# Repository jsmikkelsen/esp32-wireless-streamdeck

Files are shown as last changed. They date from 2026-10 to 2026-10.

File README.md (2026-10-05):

# ESP32 Trådløs Stream Deck & Audio Mixer

Et trådløst, tilpasseligt DIY Stream Deck og 4-kanals audio mixer bygget på en **ESP32**, **12x MX-taster** (i 3x4 anti-ghosting matrix med dioder), **4x potentiometre** og et **SSD1306 128x64 OLED-display**.

Projektet forbinder trådløst til din PC via Wi-Fi og en ultra-lav latens WebSocket-forbindelse. Du kan give enheden strøm fra en hvilken som helst 5V USB-oplader eller powerbank – **uden at have et kabel i computeren**.

---

## 🌟 Nøglefunktioner

* **Trådløs frihed:** Kører over lokalt Wi-Fi (svartid typisk 2-5 ms).
* **4-kanals hardware mixer:** Fysiske drejeknapper til individuel styring af f.eks. Master, Discord, Spotify og Browser.
* **Dynamisk OLED-dashboard:** 128x64 display viser 4 vertikale volumensøjler med live procenttal og kanalnavne.
* **12 programmerbare MX-taster:** 3x4 matrix med 1N4148-dioder for fuld anti-ghosting (N-key rollover).
* **Ingen gen-flashing påkrævet:** Handlinger og app-lydstyring konfigureres i `config.json` på din PC. Ret filen, og ændringerne træder i kraft med det samme!
* **Støjfri potentiometre:** Softwaren benytter Exponential Moving Average (EMA) filtrering og deadband, så lydstyrken aldrig flimrer.

---

## 📁 Projektstruktur

```text
esp32-wireless-streamdeck/
├── 3D/                           # 3D-filer til kabinet (STL, OpenSCAD og generator)
│   ├── streamdeck_top_plate.stl  # Topplade klar til 3D-print
│   ├── streamdeck_bottom_case.stl# Bundkabinet med USB-port klar til 3D-print
│   ├── generate_case.py          # Python STL generator
│   ├── streamdeck_case.scad      # Parametrisk OpenSCAD kildekode
│   └── README.md                 # Print- og monteringsvejledning
├── docs/
│   └── WIRING.md                 # Komplet lodde- og kablingsguide med diagrammer
├── firmware/
│   ├── platformio.ini            # PlatformIO projektfil
│   ├── src/
│   │   └── main.cpp              # C++ firmware kildekode
│   └── firmware.ino              # Samme firmware som Arduino IDE sketch
├── pc_server/
│   ├── config.json               # Konfiguration af taster og lydkanaler (ret her!)
│   ├── requirements.txt          # Python afhængigheder
│   └── streamdeck_server.py      # Baggrundsserver på PC (WebSocket + Audio + Hotkeys)
├── .gitignore
└── README.md
```

---

## 🛠️ Hardware Komponenter

1. **ESP32 DevKit** (NodeMCU-32S / ESP32-WROOM-32)
2. **12x Cherry MX kompatible switches**
3. **12x Dioder** (f.eks. 1N4148)
4. **4x Drejepotentiometre** (10k lineære)
5. **1x 0.96" I2C OLED display (SSD1306 128x64)**

Se [docs/WIRING.md](docs/WIRING.md) for detaljerede instruktioner om pin-forbindelser og lodning.

---

## 🚀 Hurtigstart Guide

### Trin 1: Kabling
Følg oversigten i [docs/WIRING.md](docs/WIRING.md).
* **Vigtigt:** Potentiometre forbindes til **3.3V** og ADC1-pinnene (**GPIO 32, 33, 34, 35**).
* **OLED:** SDA -> GPIO 21, SCL -> GPIO 22.

---

### Trin 2: Flash ESP32 Firmware

Åbn projektet i **PlatformIO** (VS Code) eller **Arduino IDE**:

1. Åbn `firmware/src/main.cpp` (eller `firmware/firmware.ino`).
2. Ret Wi-Fi oplysningerne og din PC's lokale IP-adresse:
   ```cpp
   const char* WIFI_SSID     = "DIT_WIFI_NAVN";      // 2.4 GHz Wi-Fi netværk
   const char* WIFI_PASSWORD = "DIT_WIFI_KODE";
   const char* PC_HOST       = "192.168.1.100";     // Din PC's lokale IPv4 adresse
   const int   WS_PORT       = 8765;
   ```
3. Upload koden til din ESP32.

> **Biblioteker til Arduino IDE:**
> * `Adafruit SSD1306` & `Adafruit GFX Library`
> * `WebSockets` af Markus Sattler
> * `ArduinoJson` (v6 eller nyere)

---

### Trin 3: Start PC Companion Serveren

På din PC (Windows anbefales for app-volumen):

1. Åbn en terminal / kommandoprompt i mappen `pc_server/`.
2. Installer kravene:
   ```bash
   pip install -r requirements.txt
   ```
3. Start serveren:
   ```bash
   python streamdeck_server.py
   ```
Serveren lytter nu på port `8765`. Når din ESP32 tænder, forbinder den automatisk, og skærmen opdateres!

---

### Trin 4: Tilpas dine taster og lydkanaler

Åbn `pc_server/config.json` i din foretrukne teksteditor:

```json
{
  "channels": [
    { "label": "MST", "target": "master" },
    { "label": "DIS", "target": "discord.exe" },
    { "label": "SPT", "target": "spotify.exe" },
    { "label": "APP", "target": "chrome.exe" }
  ],
  "keys": {
    "1": { "name": "Play/Pause", "action": "media_play_pause" },
    "2": { "name": "Mute Mic", "action": "hotkey", "keys": ["ctrl", "shift", "m"] },
    "3": { "name": "Lommeregner", "action": "launch", "cmd": "calc.exe" }
  }
}
```

* **Understøttede handlinger for taster:**
  * `"action": "hotkey"` med `"keys": ["ctrl", "alt", "del"]`
  * `"action": "media_play_pause"`, `"media_next"`, `"media_prev"`, `"media_mute"`
  * `"action": "launch"` med et vilkårligt program eller script i `"cmd"`

---

## 🔍 Fejlfinding

* **ESP32 kan ikke forbinde til Wi-Fi:**
  * ESP32 understøtter kun **2.4 GHz Wi-Fi** (ikke 5 GHz). Sørg for at dit netværk udsender 2.4 GHz.
* **ESP32 viser "Connecting..." på skærmen:**
  * Tjek at `PC_HOST` i firmwaren matcher computerens IP (`ipconfig` i Windows kommandoprompt).
  * Tjek at Windows Firewall ikke blokerer for port `8765`.
* **Potentiometer-værdier virker ikke under Wi-Fi:**
  * Sørg for at potentiometrene er forbundet til GPIO 32-35 (ADC1). Pins på ADC2 (f.eks. GPIO 2, 4, 12-15) virker ikke når Wi-Fi er tændt.

---

## 📜 Licens
MIT

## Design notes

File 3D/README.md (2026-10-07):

# 3D Print Ergonomisk Kabinet (Wedge Enclosure)

Denne mappe indeholder de færdige 3D-filer samt kildekoden til det vinklede skrivebordskabinet til **ESP32 Wireless Stream Deck & Audio Mixer**.

Designet er udformet som en klassisk ergonomisk **wedge/kile** med en hældningsvinkel på ca. **22 grader** mod brugeren, præcis som professionelle Stream Decks og macropads:

* **Ergonomisk vinkel:** Lav forkant (**18 mm**) for behagelig håndstilling og høj bagkant (**50 mm**) for optimal synsvinkel til OLED-displayet og tasterne.
* **Planforsænket topplade:** Toppladen med taster og potentiometre hviler på en 3 mm forsænket indvendig hylde med en flot omkransende kant.
* **Layout (venstre):** 12x Cherry MX switches i 4x3 matrix (14.2 mm snap-fit huller med standard 19.05 mm pitch).
* **Layout (højre):**
  * **Øverst:** 2x Potentiometre (Master & Discord) med 7.5 mm huller.
  * **Midt:** 1x 0.96" SSD1306 OLED-display (26 x 14 mm vindue).
  * **Nederst:** 2x Potentiometre (Spotify & Browser/App) med 7.5 mm huller.
* **Bagvæg:** 14.0 x 8.0 mm USB-port udskæring til strømforsyning af ESP32'eren.

---

## 📦 Filer i mappen

* `streamdeck_top_plate.stl` - Færdig, lukket (manifold) STL til toppladen.
* `streamdeck_bottom_case.stl` - Færdig, lukket (manifold) STL til det vinklede wedge-kabinet med USB-port og indvendig hylde.
* `generate_case.py` - Python-script der genererer de to 100% vandtætte/manifold STL-filer fra bunden (kræver ingen eksterne biblioteker).
* `streamdeck_case.scad` - Parametrisk OpenSCAD-kildekode til justering af vinkel, dimensioner eller tolerancer.

---

## 🖨️ Anbefalede 3D Print Indstillinger

| Indstilling | Anbefaling |
| :--- | :--- |
| **Materiale** | PLA eller PETG |
| **Lagtykkelse (Layer Height)** | `0.20 mm` |
| **Perimeters / Vægge** | `3` til `4` perimetre for maksimal styrke |
| **Top / Bund lag** | `4` eller `5` lag |
| **Infill** | `20%` (Gyroid eller Grid) |
| **Supports (Understøttelse)** | **Ingen nødvendig!** Begge dele er designet til at printe helt uden supports. |

### Orienteringsguide på byggepladen:
* **Top-plade (`streamdeck_top_plate.stl`):** Lægges fladt ned på byggepladen.
* **Bund-kabinet (`streamdeck_bottom_case.stl`):** Printes stående fladt på bunden. Da alle yder- og indervægge er lodrette og overkanten blot skråner 22°, kræves der **ingen support-materiale overhovedet**.

---

## 🔧 Montering og Samling

1. **MX Taster:** Trykkes i toppladen fra oversiden (klikker fast i 14.2 x 14.2 mm åbningerne).
2. **Potentiometre:** Føres op igennem 7.5 mm hullerne fra bagsiden og spændes fast med de medfølgende M7 møtrikker og skiver.
3. **OLED Skærm:** Monteres under displayvinduet med en lille dråbe varmelim eller dobbeltsidet tape mod skærmens PCB-ramme.
4. **Lodning:** Følg kablingen i [docs/WIRING.md](../docs/WIRING.md) (diodekatode mod rækker, potentiometre til ADC1 GPIO 32-35).
5. **ESP32:** Lægges i bunden af kabinettet, så USB-porten peger ud gennem åbningen på bagvæggen.
6. **Samling:** Toppladen lægges ned på den indvendige hylde i kabinettet og fastgøres med 4 stk. **M3 skruer** i hjørnerne.

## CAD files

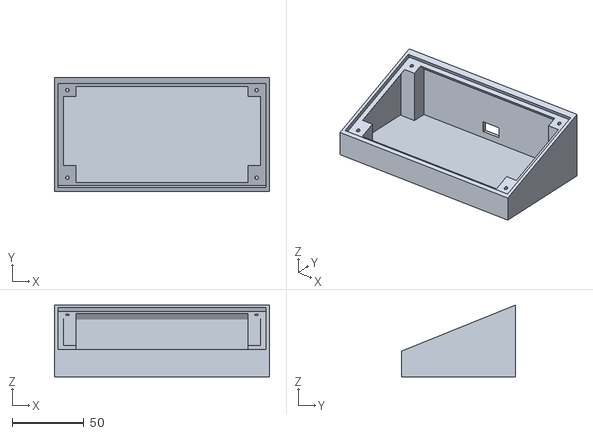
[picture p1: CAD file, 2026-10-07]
3D/streamdeck_bottom_case.stl
150.0 x 79.2 x 50.0

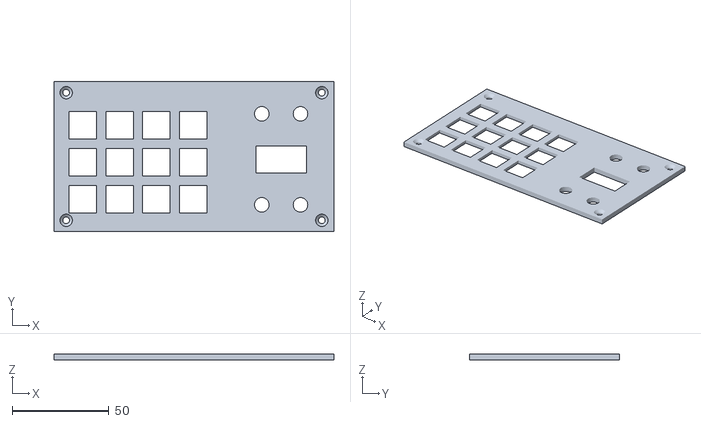
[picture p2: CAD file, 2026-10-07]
3D/streamdeck_top_plate.stl
144.6 x 77.3 x 3.00

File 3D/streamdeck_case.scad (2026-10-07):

// ===================================================================
// ESP32 Wireless Stream Deck & Audio Mixer - Angled Wedge Enclosure
// OpenSCAD Parametric Model
// ===================================================================

// Hvad vil du vise? ("both", "top", "bottom")
part = "both"; // ["both", "top", "bottom"]

// --- Hoveddimensioner for Wedge Kabinet ---
case_width       = 152.0;
case_depth       = 86.0;
front_height     = 18.0;  // Lav forkant mod brugeren
back_height      = 50.0;  // Høj bagkant (giver ~22 graders ergonomisk vinkel)
wall_thickness   = 3.0;
floor_thickness  = 2.5;
plate_recess     = 3.0;   // Hvor dybt toppladen er planforsænket
shelf_width      = 4.0;   // Hyldebredde som toppladen hviler på

// --- Dimensioner for Toppladen ---
plate_width      = 145.0;
plate_length     = 85.0;
plate_thickness  = 3.0;

// --- MX Taster (4 kolonner x 3 rækker) ---
switch_hole_size = 14.2;   // 14.0 mm nominel, 14.2 mm giver ideelt snap-fit i 3D print
switch_pitch_x   = 19.05;  // Standard 1U tastatur pitch
switch_pitch_y   = 19.05;
keys_origin_x    = 16.0;   // Første kolonne center
keys_origin_y    = 23.45;  // Første række center

// --- Potentiometre (4 stk) ---
pot_hole_d       = 7.5;    // M7 gevind med frigang
pot_x1           = 100.0;
pot_x2           = 128.0;
pot_y_top        = 61.55;  // På linje med øverste tasterække
pot_y_bottom     = 23.45;  // På linje med nederste tasterække

// --- 0.96" OLED Display (SSD1306) ---
oled_center_x    = 114.0;
oled_center_y    = 42.50;  // På linje med midterste tasterække
oled_window_w    = 26.0;
oled_window_h    = 14.0;

// --- Montage & Skruer ---
screw_hole_d     = 3.4;    // M3 gennemgående hul
corner_inset_x   = 5.5;
corner_inset_y   = 5.5;

// --- USB Port (på bagvæggen) ---
usb_w            = 14.0;
usb_h            = 8.0;
usb_x            = case_width / 2; // Centreret bagpå

$fn = 60; // Giver meget pæne, glatte runde huller i 3D-printet

// ===================================================================
// MODULER
// ===================================================================

// Kile-polyeder (hollow eller solid)
module wedge_poly(w, d, hf, hb) {
    polyhedron(
        points = [
            [0, 0, 0],   [w, 0, 0],   [w, d, 0],   [0, d, 0],   // 0, 1, 2, 3 (Bund)
            [0, 0, hf],  [w, 0, hf],  [w, d, hb],  [0, d, hb]   // 4, 5, 6, 7 (Skrå top)
        ],
        faces = [
            [0, 3, 2, 1], // Bund
            [0, 1, 5, 4], // Front
            [1, 2, 6, 5], // Højre
            [2, 3, 7, 6], // Bagside
            [3, 0, 4, 7], // Venstre
            [4, 5, 6, 7]  // Skrå overside
        ]
    );
}

module top_plate() {
    difference() {
        // Hovedplade
        cube([plate_width, plate_length, plate_thickness]);

        // 12x MX Switch huller
        for (r = [0 : 2]) {
            for (c = [0 : 3]) {
                translate([
                    keys_origin_x + c * switch_pitch_x - switch_hole_size / 2,
                    keys_origin_y + r * switch_pitch_y - switch_hole_size / 2,
                    -1
                ])
                cube([switch_hole_size, switch_hole_size, plate_thickness + 2]);
            }
        }

        // 4x Potentiometer huller
        translate([pot_x1, pot_y_top, -1])    cylinder(d = pot_hole_d, h = plate_thickness + 2);
        translate([pot_x2, pot_y_top, -1])    cylinder(d = pot_hole_d, h = plate_thickness + 2);
        translate([pot_x1, pot_y_bottom, -1]) cylinder(d = pot_hole_d, h = plate_thickness + 2);
        translate([pot_x2, pot_y_bottom, -1]) cylinder(d = pot_hole_d, h = plate_thickness + 2);

        // OLED skærm vindue
        translate([
            oled_center_x - oled_window_w / 2,
            oled_center_y - oled_window_h / 2,
            -1
        ])
        cube([oled_window_w, oled_window_h, plate_thickness + 2]);

        // 4x Hjørneskruehuller
        translate([corner_inset_x, corner_inset_y, -1]) cylinder(d = screw_hole_d, h = plate_thickness + 2);
        translate([plate_width - corner_inset_x, corner_inset_y, -1]) cylinder(d = screw_hole_d, h = plate_thickness + 2);
        translate([corner_inset_x, plate_length - corner_inset_y, -1]) cylinder(d = screw_hole_d, h = plate_thickness + 2);
        translate([plate_width - corner_inset_x, plate_length - corner_inset_y, -1]) cylinder(d = screw_hole_d, h = plate_thickness + 2);
    }
}

module bottom_wedge_case() {
    slope = (back_height - front_height) / case_depth;

    difference() {
        // Ydre kile
        wedge_poly(case_width, case_depth, front_height, back_height);

        // Forsænket hylde til toppladen
        translate([wall_thickness, wall_thickness, 0]) {
            wedge_poly(
                case_width - 2 * wall_thickness,
                case_depth - 2 * wall_thickness,
                front_height + wall_thickness * slope - plate_recess,
                back_height - wall_thickness * slope - plate_recess
            );
        }

        // Indvendigt hulrum ned til bunden
        inner_margin = wall_thickness + shelf_width;
        translate([inner_margin, inner_margin, floor_thickness]) {
            cube([
                case_width - 2 * inner_margin,
                case_depth - 2 * inner_margin,
                back_height + 10
            ]);
        }

        // USB-port åbning på bagvæggen (Gennemgående hul!)
        translate([usb_x - usb_w / 2, case_depth - wall_thickness - shelf_width - 1, floor_thickness])
            cube([usb_w, wall_thickness + shelf_width + 2, usb_h]);
    }
}

// ===================================================================
// RENDER VALG
// ===================================================================

if (part == "both") {
    // Viser kassen samlet med toppladen placeret skråt i kabinettet
    color("DimGray") bottom_wedge_case();
    
    // Toppladen placeret og vinklet ned i hylden
    translate([
        wall_thickness + (case_width - 2*wall_thickness - plate_width)/2,
        wall_thickness * cos(tilt_angle),
        front_height - plate_recess + 4.0 // Hævet lidt for visualisering
    ])
    rotate([tilt_angle, 0, 0])
    color("SteelBlue")
    top_plate();

} else if (part == "top") {
    // Printes fladt på byggepladen
    top_plate();
} else if (part == "bottom") {
    // Printes stående på sin flade bund uden supports
    bottom_wedge_case();
}

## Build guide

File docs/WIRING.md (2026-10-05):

# Kabling og Hardware Guide (Wiring Guide)

Denne guide forklarer trin for trin, hvordan du forbinder din **ESP32**, **12x MX-taster**, **12x dioder**, **4x potentiometre** og **0.96" OLED I2C display**.

---

## 1. Komponentliste (BOM)

* **1x ESP32 NodeMCU / DevKit** (30-pin eller 38-pin version)
* **12x Cherry MX kompatible switches**
* **12x Dioder** (f.eks. standard **1N4148** switching-dioder)
* **4x Drejepotentiometre** (10kΩ lineære anbefales, standard 3-bens)
* **1x 0.96" SSD1306 OLED Display** (128x64, I2C interface med 4 ben: GND, VCC, SCL, SDA)
* Montagetråd / jumper-ledninger
* USB-kabel til strømforsyning (5V USB-oplader eller powerbank)

---

## 2. Pinout Oversigt på ESP32

| Modul | Signal / Funktion | ESP32 GPIO | Note |
| :--- | :--- | :--- | :--- |
| **OLED (SSD1306)** | GND | **GND** | Fælles stel |
| | VCC | **3.3V** | **OBS:** Må ikke sluttes til 5V (kan brænde displayet af) |
| | SCL | **GPIO 22** | Hardware I2C Clock |
| | SDA | **GPIO 21** | Hardware I2C Data |
| **Potentiometer 0 (Master)** | Signal (midterste ben) | **GPIO 32** | ADC1_CH4 (fungerer med Wi-Fi aktivt) |
| **Potentiometer 1 (Discord)** | Signal (midterste ben) | **GPIO 33** | ADC1_CH5 (fungerer med Wi-Fi aktivt) |
| **Potentiometer 2 (Spotify)** | Signal (midterste ben) | **GPIO 34** | ADC1_CH6 (Input-only pin på ESP32) |
| **Potentiometer 3 (App/Browser)** | Signal (midterste ben) | **GPIO 35** | ADC1_CH7 (Input-only pin på ESP32) |
| **Matrix Række 0** | Row 0 (Tast 1, 2, 3, 4) | **GPIO 13** | Output (køres LOW under scan) |
| **Matrix Række 1** | Row 1 (Tast 5, 6, 7, 8) | **GPIO 14** | Output |
| **Matrix Række 2** | Row 2 (Tast 9, 10, 11, 12)| **GPIO 27** | Output |
| **Matrix Kolonne 0** | Col 0 (Tast 1, 5, 9) | **GPIO 18** | Input med intern `INPUT_PULLUP` |
| **Matrix Kolonne 1** | Col 1 (Tast 2, 6, 10) | **GPIO 19** | Input med intern `INPUT_PULLUP` |
| **Matrix Kolonne 2** | Col 2 (Tast 3, 7, 11) | **GPIO 23** | Input med intern `INPUT_PULLUP` |
| **Matrix Kolonne 3** | Col 3 (Tast 4, 8, 12) | **GPIO 25** | Input med intern `INPUT_PULLUP` |

---

## 3. MX Taster & 3x4 Matrix med Dioder

Ved at bruge en **3x4 switch matrix** behøver vi kun 7 GPIO-pins i stedet for 12. Dioderne forhindrer "ghosting", så du kan trykke på flere taster samtidig.

### Dioderetning (Katode mod Række)
En 1N4148 diode har en sort/farvet ring i den ene ende (**katoden**):
```text
        Anode (+)                Katode (-) med ring
          [=====]---------------------[ | ]-----------------> Til Række (Row)
```

### Lodning på hver switch:
1. **Ben 1 på switchen:** Loddes direkte til **Kolonne-ledningen (Col)**.
2. **Ben 2 på switchen:** Loddes til diodens **anode** (enden uden ring).
3. **Diodens katode** (enden med ring): Loddes til **Række-ledningen (Row)**.

### Skematisk diagram:

```text
                  Col 0           Col 1           Col 2           Col 3
                (GPIO 18)       (GPIO 19)       (GPIO 23)       (GPIO 25)
                    |               |               |               |
Row 0 ----------|<--[SW 1]------|<--[SW 2]------|<--[SW 3]------|<--[SW 4]
(GPIO 13)           |               |               |               |
Row 1 ----------|<--[SW 5]------|<--[SW 6]------|<--[SW 7]------|<--[SW 8]
(GPIO 14)           |               |               |               |
Row 2 ----------|<--[SW 9]------|<--[SW 10]-----|<--[SW 11]-----|<--[SW 12]
(GPIO 27)           |               |               |               |
```

### Tast-mapping:
* **Tast 1:** Row 0, Col 0
* **Tast 2:** Row 0, Col 1
* **Tast 3:** Row 0, Col 2
* **Tast 4:** Row 0, Col 3
* **Tast 5:** Row 1, Col 0
* **Tast 6:** Row 1, Col 1
* **Tast 7:** Row 1, Col 2
* **Tast 8:** Row 1, Col 3
* **Tast 9:** Row 2, Col 0
* **Tast 10:** Row 2, Col 1
* **Tast 11:** Row 2, Col 2
* **Tast 12:** Row 2, Col 3

---

## 4. De 4 Potentiometre (Kritisk om ADC1)

Potentiometrene fungerer som spændingsdelere:
* **Venstre ben:** Forbindes til **GND** (fælles stel).
* **Højre ben:** Forbindes til **3.3V** (Brug ALDRIG 5V, da ESP32's analoge indgange max tåler 3.3V).
* **Midterste ben (Wiper / Signal):** Forbindes til de respektive ADC1 pins:
  * Pot 0 -> **GPIO 32**
  * Pot 1 -> **GPIO 33**
  * Pot 2 -> **GPIO 34**
  * Pot 3 -> **GPIO 35**

> **Vigtig ESP32 teknisk note:** 
> ESP32 har to analoge konvertere (ADC1 og ADC2). Når Wi-Fi aktiveres i koden, beslaglægger ESP32's Wi-Fi driver automatisk **ADC2** (GPIO 0, 2, 4, 12, 15, 25, 26). Derfor virker analoge målinger på ADC2 ikke trådløst! Vores opsætning benytter udelukkende **ADC1**, som fungerer 100% stabilt sammen med Wi-Fi.

---

## 5. OLED Display (SSD1306)

* **GND** -> ESP32 GND
* **VCC** -> ESP32 3.3V
* **SCL** -> ESP32 GPIO 22
* **SDA** -> ESP32 GPIO 21
*(Standard I2C adresse er `0x3C`).*

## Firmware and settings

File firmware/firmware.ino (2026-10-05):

#include <WiFi.h>
#include <WebSocketsClient.h>
#include <ArduinoJson.h>
#include <Wire.h>
#include <Adafruit_GFX.h>
#include <Adafruit_SSD1306.h>

// ==========================================
// KONFIGURATION (Rettes til dit netværk / PC)
// ==========================================
const char* WIFI_SSID     = "DIT_WIFI_NAVN";
const char* WIFI_PASSWORD = "DIT_WIFI_KODE";
const char* PC_HOST       = "192.168.1.100"; // Din PC's lokale IP-adresse
const int   WS_PORT       = 8765;

// ==========================================
// OLED DISPLAY (SSD1306 128x64 I2C)
// ==========================================
#define SCREEN_WIDTH 128
#define SCREEN_HEIGHT 64
#define OLED_RESET -1
Adafruit_SSD1306 display(SCREEN_WIDTH, SCREEN_HEIGHT, &Wire, OLED_RESET);

// ==========================================
// HARDWARE PINS
// ==========================================
// Potentiometre SKAL sidde på ADC1 (GPIO 32-39), da ADC2 deaktiveres ved Wi-Fi brug!
const int POT_PINS[4] = {32, 33, 34, 35};

// 3x4 Switch Matrix (Row-driven LOW, Cols INPUT_PULLUP med dioder)
const int ROW_PINS[3] = {13, 14, 27};
const int COL_PINS[4] = {18, 19, 23, 25};

// ==========================================
// TILSTAND OG VARIABLER
// ==========================================
WebSocketsClient webSocket;
bool wsConnected = false;

// Volumen- og kanaldata (0-100%)
int currentVolume[4] = {50, 50, 50, 50};
int lastFilteredPot[4] = {-1, -1, -1, -1};
float potSmoothed[4] = {50.0, 50.0, 50.0, 50.0};
char channelLabels[4][8] = {"MST", "DIS", "SPT", "APP"};

// Matrix tilstand
bool keyState[3][4] = {false};
unsigned long lastDebounceTime[3][4] = {0};
const unsigned long DEBOUNCE_DELAY = 25; // ms

// ==========================================
// OLED TEGNERUTINE
// ==========================================
void drawDashboard() {
  display.clearDisplay();

  display.setTextSize(1);
  display.setTextColor(SSD1306_WHITE);

  for (int i = 0; i < 4; i++) {
    int colWidth = 32;
    int x = i * colWidth;

    // Kanalnavn (f.eks. MST, DIS, SPT, APP)
    display.setCursor(x + 4, 0);
    display.print(channelLabels[i]);

    // Lydstyrke i procent (0-100)
    display.setCursor(x + 4, 11);
    if (currentVolume[i] < 10) {
      display.print(" ");
    }
    display.print(currentVolume[i]);
    display.print("%");

    // Lydsøjle ramme (bredde: 16px, højde: 42px, y: 22 til 63)
    display.drawRect(x + 8, 21, 16, 43, SSD1306_WHITE);

    // Beregn fyldhøjde (0 til 39 pixels indvendigt)
    int fillHeight = map(currentVolume[i], 0, 100, 0, 39);
    fillHeight = constrain(fillHeight, 0, 39);

    if (fillHeight > 0) {
      display.fillRect(x + 10, 21 + (39 - fillHeight) + 2, 12, fillHeight, SSD1306_WHITE);
    }
  }

  // Lille forbindelsesindikator i bunden hvis WebSocket ikke er forbundet
  if (!wsConnected) {
    display.fillRect(0, 62, 128, 2, SSD1306_WHITE);
  }

  display.display();
}

// ==========================================
// WEBSOCKET HÅNDTERING
// ==========================================
void webSocketEvent(WStype_t type, uint8_t * payload, size_t length) {
  switch (type) {
    case WStype_DISCONNECTED:
      Serial.println("[WS] Disconnected!");
      wsConnected = false;
      drawDashboard();
      break;

    case WStype_CONNECTED:
      Serial.printf("[WS] Connected to: %s\n", payload);
      wsConnected = true;
      drawDashboard();
      break;

    case WStype_TEXT: {
      StaticJsonDocument<512> doc;
      DeserializationError err = deserializeJson(doc, payload);
      if (!err) {
        // Opdater kanal-volumen sendt fra PC
        if (doc.containsKey("vol") && doc.containsKey("ch")) {
          int ch = doc["ch"];
          int vol = doc["vol"];
          if (ch >= 0 && ch < 4) {
            currentVolume[ch] = constrain(vol, 0, 100);
            drawDashboard();
          }
        }
        // Opdater kanalnavne hvis sendt fra PC
        if (doc.containsKey("labels")) {
          JsonArray labels = doc["labels"].as<JsonArray>();
          for (int i = 0; i < 4 && i < (int)labels.size(); i++) {
            const char* lbl = labels[i];
            strncpy(channelLabels[i], lbl, sizeof(channelLabels[i]) - 1);
            channelLabels[i][sizeof(channelLabels[i]) - 1] = '\0';
          }
          drawDashboard();
        }
      }
      break;
    }

    default:
      break;
  }
}

// ==========================================
// 3x4 MATRIX SCANNER (MED DIODER & DEBOUNCE)
// ==========================================
void scanMatrix() {
  unsigned long now = millis();

  for (int r = 0; r < 3; r++) {
    digitalWrite(ROW_PINS[r], LOW);
    delayMicroseconds(5);

    for (int c = 0; c < 4; c++) {
      bool isReadingLow = (digitalRead(COL_PINS[c]) == LOW);

      if (isReadingLow != keyState[r][c]) {
        if ((now - lastDebounceTime[r][c]) > DEBOUNCE_DELAY) {
          lastDebounceTime[r][c] = now;
          keyState[r][c] = isReadingLow;

          int keyNum = (r * 4) + c + 1;

          StaticJsonDocument<128> doc;
          doc["type"] = "key";
          doc["key"] = keyNum;
          doc["state"] = isReadingLow ? "down" : "up";

          String jsonStr;
          serializeJson(doc, jsonStr);

          if (wsConnected) {
            webSocket.sendTXT(jsonStr);
          }
          Serial.printf("Key %d: %s\n", keyNum, isReadingLow ? "PRESSED" : "RELEASED");
        }
      }
    }

    digitalWrite(ROW_PINS[r], HIGH);
  }
}

// ==========================================
// POTENTIOMETER FILTER & AFLÆSNING
// ==========================================
void readPotentiometers() {
  static unsigned long lastCheck = 0;
  if (millis() - lastCheck < 30) return;
  lastCheck = millis();

  for (int i = 0; i < 4; i++) {
    int raw = analogRead(POT_PINS[i]);

    // Exponential moving average filter (EMA)
    potSmoothed[i] = (0.25f * raw) + (0.75f * potSmoothed[i]);

    int val = map((int)potSmoothed[i], 20, 4075, 0, 100);
    val = constrain(val, 0, 100);

    if (abs(val - lastFilteredPot[i]) >= 2) {
      lastFilteredPot[i] = val;
      currentVolume[i] = val;

      StaticJsonDocument<128> doc;
      doc["type"] = "pot";
      doc["pot"] = i;
      doc["val"] = val;

      String jsonStr;
      serializeJson(doc, jsonStr);

      if (wsConnected) {
        webSocket.sendTXT(jsonStr);
      }

      drawDashboard();
    }
  }
}

// ==========================================
// SETUP
// ==========================================
void setup() {
  Serial.begin(115200);

  Wire.begin(21, 22);
  if (!display.begin(SSD1306_SWITCHCAPVCC, 0x3C)) {
    Serial.println("SSD1306 init failed!");
  }
  display.clearDisplay();
  display.setTextColor(SSD1306_WHITE);
  display.setTextSize(1);
  display.setCursor(10, 15);
  display.println("ESP32 StreamDeck");
  display.setCursor(10, 35);
  display.println("Connecting WiFi...");
  display.display();

  for (int r = 0; r < 3; r++) {
    pinMode(ROW_PINS[r], OUTPUT);
    digitalWrite(ROW_PINS[r], HIGH);
  }
  for (int c = 0; c < 4; c++) {
    pinMode(COL_PINS[c], INPUT_PULLUP);
  }

  for (int i = 0; i < 4; i++) {
    pinMode(POT_PINS[i], INPUT);
    int initialRaw = analogRead(POT_PINS[i]);
    potSmoothed[i] = initialRaw;
    int initialVal = map(initialRaw, 20, 4075, 0, 100);
    initialVal = constrain(initialVal, 0, 100);
    lastFilteredPot[i] = initialVal;
    currentVolume[i] = initialVal;
  }

  WiFi.mode(WIFI_STA);
  WiFi.begin(WIFI_SSID, WIFI_PASSWORD);

  int attempts = 0;
  while (WiFi.status() != WL_CONNECTED && attempts < 30) {
    delay(300);
    attempts++;
  }

  display.clearDisplay();
  display.setCursor(10, 20);
  if (WiFi.status() == WL_CONNECTED) {
    display.println("WiFi OK!");
    display.setCursor(10, 35);
    display.print("IP: ");
    display.println(WiFi.localIP());
  } else {
    display.println("WiFi Failed!");
    display.setCursor(10, 35);
    display.println("Check SSID/Pass");
  }
  display.display();
  delay(1000);

  webSocket.begin(PC_HOST, WS_PORT, "/");
  webSocket.onEvent(webSocketEvent);
  webSocket.setReconnectInterval(3000);

  drawDashboard();
}

void loop() {
  webSocket.loop();
  scanMatrix();
  readPotentiometers();
}

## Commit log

2026-10-05 Initial commit: ESP32 wireless streamdeck & audio mixer
2026-10-05 Add 3D printable enclosure: STL models, OpenSCAD file, and generator script
    [streamdeck_bottom_case.stl, streamdeck_case.scad, streamdeck_top_plate.stl]
2026-10-07 Update enclosure to angled ergonomic wedge design (~22 degree tilt)
    [streamdeck_bottom_case.stl, streamdeck_case.scad, streamdeck_top_plate.stl]
2026-10-07 Fix USB through-hole and update top plate with round holes and keycap clearance
    [streamdeck_top_plate.stl]
2026-10-07 Fix USB through-hole and smooth round holes via OpenSCAD
    [streamdeck_bottom_case.stl, streamdeck_case.scad, streamdeck_top_plate.stl]
